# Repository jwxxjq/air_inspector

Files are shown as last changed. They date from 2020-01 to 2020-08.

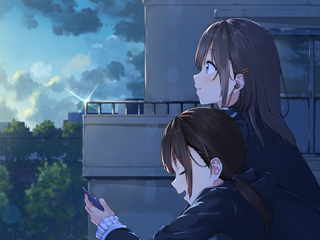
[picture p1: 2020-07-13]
host_pc_script/fig0.png

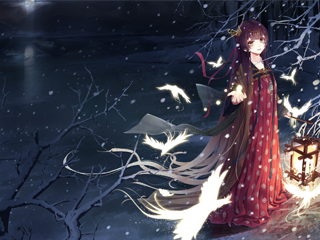
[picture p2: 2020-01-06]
host_pc_script/fig4.png

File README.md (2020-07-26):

# air_inspector
indoor air quility inspector for PM2.5/PM10/CO2/CH2O/TEMP/RH

comptable with self-build ESPEasy version: https://github.com/jwxxjq/ESPEasy

hardware:

    Temperature Sensor: SHT31
    
    Dust Sensor: PMS7003
    
    CH2O Sensor: ZE08
    
    CO2 Sensor: MH-Z19B

    mcu: ATmega328P (running Arduino)

    displayer: 320*240 ILI9341

    flash: W25Q16JVSSIG

    wifi connector: ESP8266

lib necessary:

    python:

        serial
  
        matplotlib
  
    Arduino:

        SPIMemory
  
        Adafruit_ILI9341
        
        Adafruit_GFX_Library
        
        Adafruit_SHT31
        
        MHZ19
        
        PMS
        
PCB projcet:

    https://oshwhub.com/jwxxjq/air_inspector

STEPS:

1. write fig data into flash

    A. prepare fig0~9.png (must be 240*320)
  
    B. excute host_pc_script/trans_png_to_bin.py, output figx.bin
    
    C. edit host_pc_script/uart_write.py
    
        a. COM port @ line 25
    
        b. baud rate @ line 27 (should match step D)
    
        c. do not excute right now
  
    D. edit uart_write_flash/uart_write_flash.ino
  
        a. BAUD_TATE @ line 6 (should match step C above)
    
        b. load into MCU
    
        c. then excute host_pc_script/uart_write.py, wait all lines finish
    
    E. if checksum error happens, may need to slow down the baud rate
  
2. load main program to MCU

    A. load air_inspector/air_inspector.ino to MCU
    
3. flash ESP8266 with this version: https://github.com/jwxxjq/ESPEasy

    A. select Environment - custom_sensor in Devices page, RX pin: 3, TX pin: 1
    
    B. other settings same with orginal ESPEasy(https://github.com/letscontrolit/ESPEasy) (like MQTT or others)

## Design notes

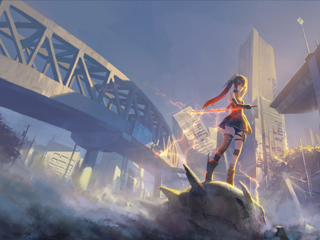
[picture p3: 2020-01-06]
host_pc_script/fig1.png

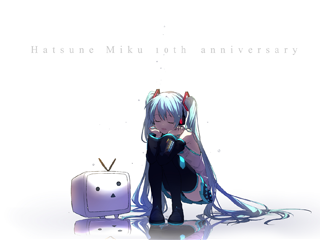
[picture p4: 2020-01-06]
host_pc_script/fig8.png

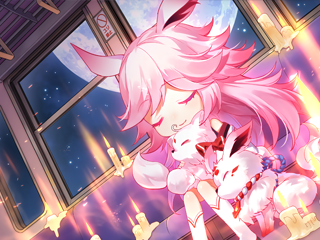
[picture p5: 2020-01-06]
host_pc_script/fig7.png

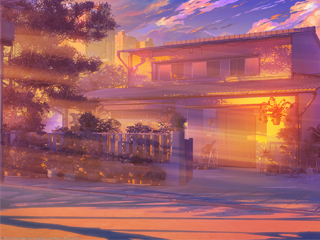
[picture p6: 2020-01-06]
host_pc_script/fig5.png

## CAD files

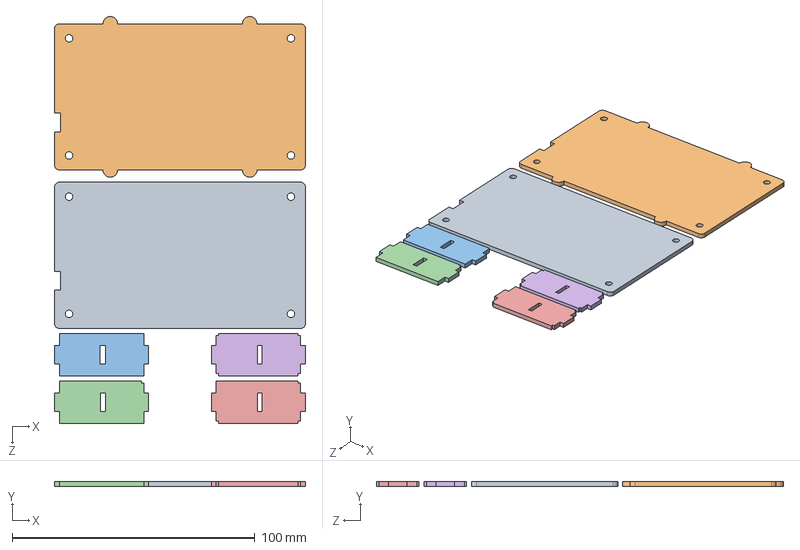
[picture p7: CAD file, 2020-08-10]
shell/compose_for_cut.SLDASM
103.5 x 2.00 x 167.8 mm
back
front
side
side_2
side_4
side_5

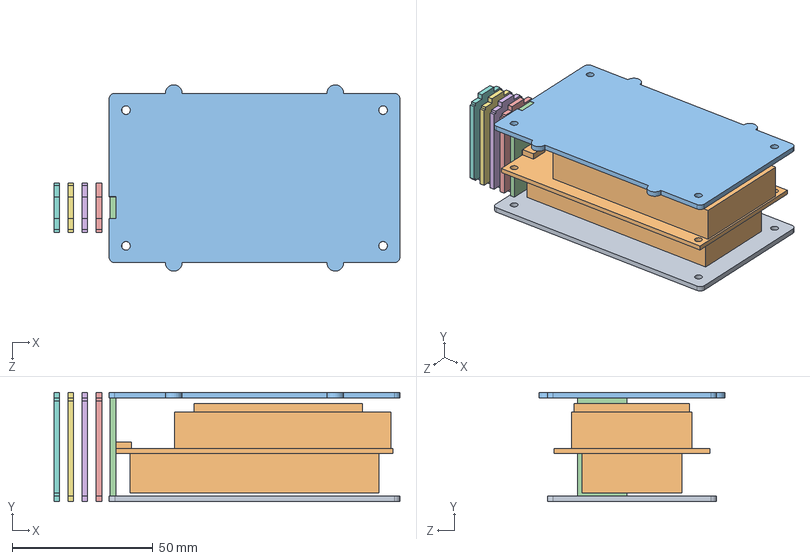
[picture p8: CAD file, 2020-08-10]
shell/assembly.SLDASM
123.1 x 38.8 x 66.3 mm
back
main_board
front
side
side_2
side_3
side_4
side_5

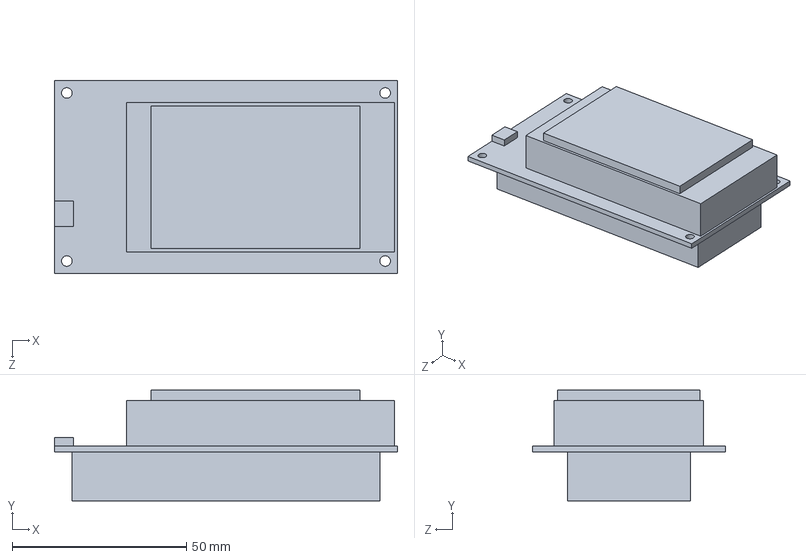
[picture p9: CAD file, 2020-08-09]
shell/main_board.SLDPRT
98.6 x 31.8 x 55.4 mm

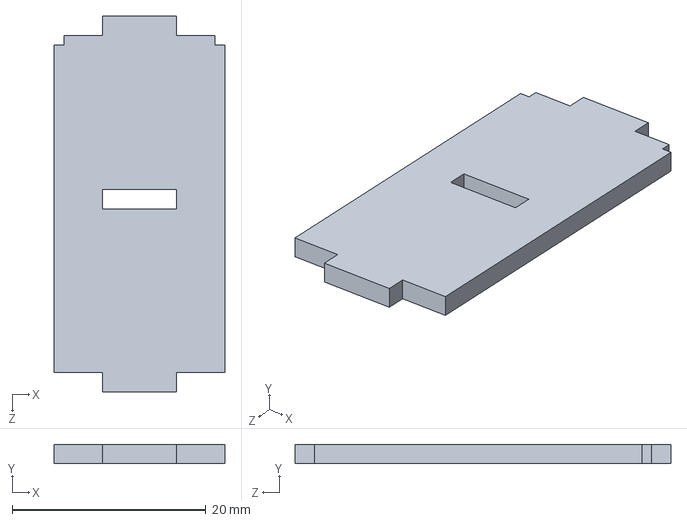
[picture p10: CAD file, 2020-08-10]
shell/side_3.SLDPRT
17.6 x 2.00 x 38.8 mm

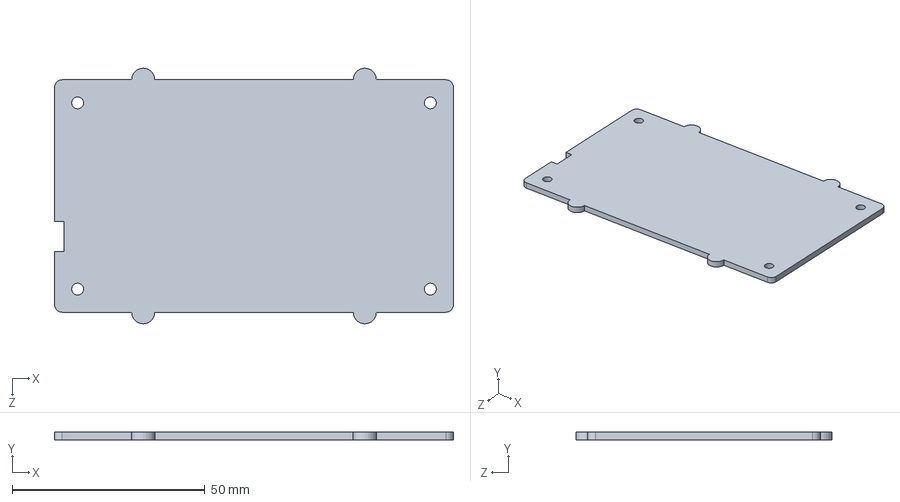
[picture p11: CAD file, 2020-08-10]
shell/front.SLDPRT
103.5 x 2.00 x 66.3 mm

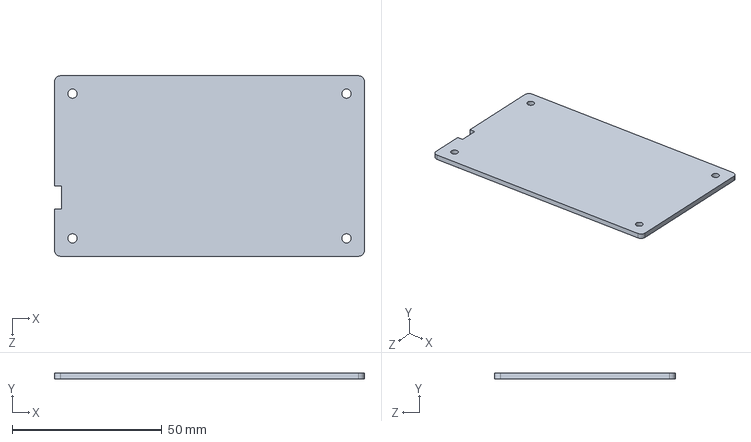
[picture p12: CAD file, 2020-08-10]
shell/back.SLDPRT
103.5 x 2.00 x 60.3 mm

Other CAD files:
shell/side_5.SLDPRT
shell/side_2.SLDPRT
shell/side_4.SLDPRT
shell/side.SLDPRT
shell/compose_for_cut.DWG
shell/compose_for_cut.SLDDRW

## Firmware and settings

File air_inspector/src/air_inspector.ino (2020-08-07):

#include "define.h"
#include "stdlib.h"

//TW07ST u_TW07ST;
SERSOR_SERIAL u_SERSOR_SERIAL(3,2);
MHZ19_SW_UART mhz19_sw_uart(8,7);
display_flash u_display_flash;
Adafruit_SHT31 sht31 = Adafruit_SHT31();
sensor_group u_sensor_value_group;
PMS7003_UART pms(14, 15);
ZE08_CH2O u_ZE08(5,6); //5: RXM, 6: TXM

unsigned long last_update_fig_time;
bool flag_to_update_fig; //set ture when need to update fig; set to false when one fig is updated
bool sensor_enable;

void setup() {
  // put your setup code here, to run once:
  //display related
  Serial.begin(BAUD_RATE); // for debug print
  u_display_flash.init();
  
  sensor_power_on();
  //sensor init
  sht31.begin(0x44); //SHT31 init
  Serial.println("sht31 init done");

  mhz19_sw_uart.init();
  Serial.println("mhz19 init done");
  pms.init();
  Serial.println("pms init done");
  u_ZE08.init();
  Serial.println("ZE08_CH2O init done");
  u_sensor_value_group.init();

  //set timer to update backgroud fig
  flag_to_update_fig = false;
  last_update_fig_time = millis();
  Serial.println(last_update_fig_time);

  //set sensor enable
  sensor_enable = true;

  //init timer1 for LED_PWM control
  LED_PWM_timer1_init();
}

void loop() {
//  update_LED_PWM_level();
  AIR_INSPECTOR_UART_DEBUG_PRINTLN("enter loop");
  while(1){
    for (uint8_t i = 0; i < max_fig_number; i++){
      AIR_INSPECTOR_UART_DEBUG_PRINT("fig");
      AIR_INSPECTOR_UART_DEBUG_PRINTLN(i);
//      uint8_t data[2] = {1,1};
//      u_display_flash.write_bytes_to_flash(1022, data, 2);
//      Serial.println(u_display_flash.read_one_byte_from_flash(1023));

//      uint8_t data = u_display_flash.read_one_byte_from_flash(1023);
//      Serial.print("current data = ");
//      Serial.println(data);
//      data += 1;
//      u_display_flash.write_bytes_to_flash(1023, &data, 1);
//      Serial.print("write data = ");
//      Serial.println(u_display_flash.read_one_byte_from_flash(1023));
//      while(1);

      u_display_flash.update_one_fig(i);
      //set default to all-zeros
      u_display_flash.update_item_value(i, item_number_CO2,  0);
      u_display_flash.update_item_value(i, item_number_CH2O, 0);
      u_display_flash.update_item_value(i, item_number_PM25, 0);
      u_display_flash.update_item_value(i, item_number_PM10, 0);
      u_display_flash.update_item_value(i, item_number_TEMP, 0);
      u_display_flash.update_item_value(i, item_number_RH,   0);

      //update real value display
      while(!flag_to_update_fig){
        //Serial.println("waiting for sensor update");
        if (u_sensor_value_group.TEMP_value != 0 && u_sensor_value_group.RH_value != 0){
          u_display_flash.update_item_value(i, item_number_TEMP, u_sensor_value_group.TEMP_value);
          u_display_flash.update_item_value(i, item_number_RH, u_sensor_value_group.RH_value);
          u_display_flash.update_item_value(i, item_number_CO2, u_sensor_value_group.CO2_value);
          u_display_flash.update_item_value(i, item_number_PM25, u_sensor_value_group.PM25_value);
          u_display_flash.update_item_value(i, item_number_PM10, u_sensor_value_group.PM10_value);
          u_display_flash.update_item_value(i, item_number_CH2O, u_sensor_value_group.CH2O_value);
        }
        check_if_update_fig();
        update_sensor_values();

        wait_next_sensor_update(); //delay time here
        update_sensor_enable();
      }
      flag_to_update_fig = false;
      //tft.fillScreen(ILI9341_BLACK);
    }
  }
}

//read enable pin to init / disable sensor
void update_sensor_enable(){
  int temp = analogRead(7);

  if (temp > 1000){ //enable pin pull high
    if (sensor_enable){
      //enable -> enable, do nothing
      sensor_enable = true;
    }
    else{
      //disable -> enable, turn on sensor
      sensor_enable = true;
      sensor_power_on();
      delay(10);

      pms.wakeup();
      mhz19_sw_uart.init();
      u_ZE08.init();
      //AIR_INSPECTOR_UART_DEBUG_PRINTLN("sensor wakeup done");
    }
  }
  else{
    if (sensor_enable){
      //enable -> disable, enter low power
      sensor_enable = false;
      //turn off sensor power
      sensor_power_off();
      pms.sleep(); //set pms into sleep
      //delay(10);
      //AIR_INSPECTOR_UART_DEBUG_PRINTLN("enter low power mode done");
    }
    else{
      //disable -> disable, do nothing
      sensor_enable = false;
    }
  }
}
//sensor enable set
void sensor_power_on(){
  pinMode(17, OUTPUT);
  digitalWrite(17, HIGH);
}

void sensor_power_off(){
  pinMode(17, OUTPUT);
  digitalWrite(17, LOW);
}

//delay time for sensor update
//should adjust LED_PWM inside
void wait_next_sensor_update(){
  unsigned long enter_delay_time = millis();
  while(1){
    update_LED_PWM_level();
    delay(500);
    unsigned long this_time = millis();
    if (enter_delay_time + sensor_read_delay_ms < this_time){
      //AIR_INSPECTOR_UART_DEBUG_PRINTLN(enter_delay_time + sensor_read_delay_ms);
      break;
    }
    else if (enter_delay_time > this_time){
      break; //directly break when millis() return to 0x0
    }
  }
}

//set update flag to ture
void set_update_fig_flag(){
  flag_to_update_fig = true;
}

//check time duration for update fig
void check_if_update_fig(){
//  Serial.println("in check function");
  unsigned long this_time = millis();
  //AIR_INSPECTOR_UART_DEBUG_PRINTLN(this_time);
  //AIR_INSPECTOR_UART_DEBUG_PRINTLN(last_update_fig_time);
  if (this_time - last_update_fig_time > time_each_fig_ms){
    set_update_fig_flag();
    last_update_fig_time = this_time;
  }
  else if ((this_time < time_each_fig_ms) && (last_update_fig_time > time_each_fig_ms)){ // back to 0 about 50 days
    set_update_fig_flag();
    last_update_fig_time = this_time;
  }
}

void update_sensor_values(){
  //temperature & humidity
  float t = sht31.readTemperature();
  float h = sht31.readHumidity();
  uint16_t temp = uint16_t (t*100);
  uint16_t rh = uint16_t (h*100);
  u_sensor_value_group.put_temp_rh_value(temp, rh);
  
  if (sensor_enable) {
    //delay(500);
    //CO2
    //AIR_INSPECTOR_UART_DEBUG_PRINTLN("start CO2");
    uint32_t CO2_value = mhz19_sw_uart.read_CO2_value();
    AIR_INSPECTOR_UART_DEBUG_PRINT("CO2_value = ");
    AIR_INSPECTOR_UART_DEBUG_PRINTLN(CO2_value);
    if (CO2_value != 15000 && CO2_value != 0 && CO2_value != 0xffffffff){  //not 0 & 15000 & time_out
      u_sensor_value_group.put_CO2_value(CO2_value);
    }
  
    delay(500);
    //dust: PM2.5 & PM10
    //AIR_INSPECTOR_UART_DEBUG_PRINTLN("start dust");
    if (pms.update_dust_value()){
      u_sensor_value_group.put_dust_value(pms.PM25_value,pms.PM10_value);
      AIR_INSPECTOR_UART_DEBUG_PRINT("PM2.5 value = ");
      AIR_INSPECTOR_UART_DEBUG_PRINTLN(pms.PM25_value);
      AIR_INSPECTOR_UART_DEBUG_PRINT("PM10 value = ");
      AIR_INSPECTOR_UART_DEBUG_PRINTLN(pms.PM10_value);
    }
  
    delay(500);
    //CH2O
    //AIR_INSPECTOR_UART_DEBUG_PRINTLN("start CH2O");
    uint16_t CH2O_value = u_ZE08.read_CH2O_value();
    AIR_INSPECTOR_UART_DEBUG_PRINT("CH2O value = ");
    AIR_INSPECTOR_UART_DEBUG_PRINTLN(CH2O_value);
    if (CH2O_value != 0){  //heating return 0x0
      u_sensor_value_group.put_CH2O_value(CH2O_value);
    }
  }
  else{
    AIR_INSPECTOR_UART_DEBUG_PRINTLN("sensor disabled");
  }

  u_sensor_value_group.calculate_average_value();

  u_SERSOR_SERIAL.print_value(u_sensor_value_group.PM25_value, u_sensor_value_group.PM10_value,
                              u_sensor_value_group.CO2_value, u_sensor_value_group.CH2O_value,
                              u_sensor_value_group.TEMP_value, u_sensor_value_group.RH_value);

}

//timer init for LED_PWM
void LED_PWM_timer1_init(){
  pinMode(9, OUTPUT);

  #ifdef disable_LED_PWM
    digitalWrite(9, HIGH);
    AIR_INSPECTOR_UART_DEBUG_PRINTLN("LED_PWM disabled");
  #else
    #ifdef use_HW_LED_PWM
      analogWrite(9, 255);
      AIR_INSPECTOR_UART_DEBUG_PRINTLN("USE HW PWM");
    #else
      TCCR1A = 0;
      TCCR1B = 0;
      TCCR1B |= (1 << CS10) | (1 << WGM12); // CS10 -- prescaler 1, WGM12 -- CTC mode
      TIMSK1 = 0;
      TIMSK1 |= (1 << OCIE1A) | (1 << OCIE1B); // OCIE1A -- OCR1A, OCIE1B -- OCR1B
      OCR1A = MCU_xtal_freq / LED_PWA_freq - 1; // set OCR1A value, which return 0 in next cycle, change PB9 to high
      OCR1B = MCU_xtal_freq / LED_PWA_freq / 100 * 50 - 1; // set OCR1B, this will change PB9 to low, default set to 50%
    #endif
  #endif
}

//change LED PWM cycle
void LED_PWM_set(uint8_t PWM_precentage){
  if (PWM_precentage >= 100){
    PWM_precentage = 100; //max 100%
  }
  OCR1B = MCU_xtal_freq / LED_PWA_freq / 100 * PWM_precentage - 1; // set to PWA_precentage %
}

ISR(TIMER1_COMPA_vect) {
  PORTB |= B00000010; // pin 9 set HIGH
}
 
ISR(TIMER1_COMPB_vect) {
  PORTB &= B11111101; // pin 9 set LOW
}

void update_LED_PWM_level(){
  #ifdef disable_LED_PWM
    digitalWrite(9, HIGH);
  #else
    int temp = analogRead(6);
    //AIR_INSPECTOR_UART_DEBUG_PRINT("light: ");
    //AIR_INSPECTOR_UART_DEBUG_PRINTLN(temp);

    uint8_t index = 0;
    uint8_t index_max = sizeof(LED_light_in_threshold)/sizeof(LED_light_in_threshold[0]);
    //AIR_INSPECTOR_UART_DEBUG_PRINTLN(index_max);
    for(index = 0; index < index_max; index++){
      int threhold_value = LED_light_in_threshold[index]<<2;
      if (temp > threhold_value){
        continue;
      }
      else{
        //AIR_INSPECTOR_UART_DEBUG_PRINTLN(index);
        break;
      }
    }
    //AIR_INSPECTOR_UART_DEBUG_PRINT("set LED_PWM to level");
    //AIR_INSPECTOR_UART_DEBUG_PRINTLN(index);

    #ifdef use_HW_LED_PWM
      analogWrite(9, LED_birghtness[index]);
    #else
      LED_PWM_set(LED_birghtness[index]);
    #endif
  #endif
}

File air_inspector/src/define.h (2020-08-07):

#ifndef _DEFINE_
#define _DEFINE_

#include <SoftwareSerial.h>
//#include "TW07ST.h"
//#include <FlexiTimer2.h>
#include <SENSOR_SERIAL.h>
#include <display_flash.h>
#include <Adafruit_SHT31.h>
#include <sensor_group.h>
#include <MHZ19_SW_UART.h>
#include <PMS7003.h>
#include <ZE08_CH2O.h>

//Arduino peri define
#define BAUD_RATE 9600 //for serial.print

//#define disable_LED_PWM //uncomment here to disable LED_TFT PWM auto brightness adjust feature
#define use_HW_LED_PWM //HW PWM 500Hz

#define AIR_INSPECTOR_UART_DEBUG
/* Setup debug printing macros. */
#define AIR_INSPECTOR_UART_DEBUG_PRINTER Serial
#ifdef AIR_INSPECTOR_UART_DEBUG
  #define AIR_INSPECTOR_UART_DEBUG_PRINT(...) { AIR_INSPECTOR_UART_DEBUG_PRINTER.print(__VA_ARGS__); }
  #define AIR_INSPECTOR_UART_DEBUG_PRINTLN(...) { AIR_INSPECTOR_UART_DEBUG_PRINTER.println(__VA_ARGS__); }
#else
  #define AIR_INSPECTOR_UART_DEBUG_PRINT(...) {} /**< Debug Print Placeholder if Debug is disabled */
  #define AIR_INSPECTOR_UART_DEBUG_PRINTLN(...) {} /**< Debug Print Line Placeholder if Debug is disabled */
#endif

//fig fresh rate
#define time_each_fig_ms 1800000 //30*60*1000ms
//#define time_each_fig_ms 18000 //30*60*1000ms

//sensor value update rate
#define sensor_read_delay_ms 10000 //10*1000ms

//timer1 TFT_LED PWM config
#define MCU_xtal_freq 16000000
#define LED_PWA_freq 1000 //1k PWM
#ifndef use_HW_LED_PWM
  const uint8_t LED_birghtness[7] = {10, 20, 30, 40, 50, 70, 99}; //100 level
#else
//  const uint8_t LED_birghtness[7] = {40, 80, 130, 160, 190, 230, 255}; //255 level for HW PWM
  const uint8_t LED_birghtness[7] = {90, 95, 100, 105, 110, 115, 150}; //255 level for HW PWM
#endif
const uint8_t LED_light_in_threshold[6] = {40, 60, 75, 100, 125, 150}; //*4 to convert to 0~1023

#endif

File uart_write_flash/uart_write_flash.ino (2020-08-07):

#include<SoftwareSerial.h>
#include<SPIMemory.h>
#define fig_width 320
#define fig_high 240
#define BAUD_RATE 9600 //for serial.print
#define TRANS_BAUD_RATE 76800 //for softSerial
#define FLASH_CS 4 //define cs pin of flash
//#define fig_byte_number fig_high*fig_width*2 //r5g6b5, each pixel occupy 2 byte, 153600 bytes for 240*320*2
#define fig_byte_number 153664
#define max_fig_number 10
#define flash_max_size 0x200000 //2MB(16Mbit)
#define flash_size_each_fig 0x30000 //192K > 153600

#define char_lib_width 96
#define char_lib_high 200
#define char_lib_start_addr 0x1FB000 //0x1f_b000~0x1f_fb00
#define char_lib_byte_number 19200

//#define fig1_start_addr flash_max_size - 0x30000*1 //0x0 ~ 0x‭25800‬ for 240*320*2
SPIFlash flash(FLASH_CS);
SoftwareSerial softSerial(3,2);

void setup() {
  // put your setup code here, to run once:
  Serial.begin(BAUD_RATE);
  softSerial.begin(TRANS_BAUD_RATE);
  softSerial.listen();
  flash.begin();
//  uint8_t test;
//  uint32_t addr = char_lib_start_addr+0x5;
//  Serial.println(addr);
//  Serial.println(flash.readByte(addr));
//  
//  addr = char_lib_start_addr+0x4843;
//  Serial.println(addr);
//  Serial.println(flash.readByte(addr));
}

void loop() {
  // put your main code here, to run repeatedly:
  Serial.println("waiting for start");
  for (uint8_t fig_count = 0; fig_count < max_fig_number; fig_count ++){
    uint32_t byte_count = 0;
    uint32_t flash_start_addr = flash_max_size - (flash_size_each_fig * fig_count) - flash_size_each_fig;
    uint32_t offset = 0;
    while(1){
      if (softSerial.available() > 5){
        //erase flash here instead of in setup(), in case of mistach reset putton
        if (erase_flash(flash_start_addr, fig_byte_number) != true){
          Serial.println("flash erase error");
          while(1);
        }
  //      flash.eraseSection(flash_start_addr, 65536);
  //      flash.eraseSection(flash_start_addr+65536, 65536);
        //flash.eraseChip();
        break;
      }
    }
    Serial.println("flash erase done");
    while(byte_count < fig_byte_number){

      if(softSerial.available() > 31){
        uint8_t data[32];
        bool result;
        softSerial.readBytes(data, 32);
        result = flash.writeByteArray(flash_start_addr+offset, data, 32); // write 32 byte to flash
        if (result != true) {
          Serial.print("write flash error @ ");
          Serial.println(offset);
        }
        uint8_t read_data[32];
        result = flash.readByteArray(flash_start_addr+offset, read_data, 32);
        if (result != true) {
          Serial.println("read flash error @");
          Serial.println(offset);
        }
        softSerial.write(summary(read_data));
        offset += 32;
        byte_count += 32;
      }
    }
    Serial.println("one fig done");
  }
  
  Serial.println("write char_lib start");
  uint32_t byte_count = 0;
  uint32_t flash_start_addr = char_lib_start_addr;
  uint32_t offset = 0;
  while(1){
    if (softSerial.available() > 5){
      //erase flash here instead of in setup(), in case of mistach reset putton
      if (erase_flash(flash_start_addr, char_lib_byte_number) != true){
        Serial.println("flash erase error");
        while(1);
      }
      break;
    }
  }
  Serial.println("flash erase done");
  while(byte_count < char_lib_byte_number){
    if(softSerial.available() > 31){
      uint8_t data[32];
      bool result;
      softSerial.readBytes(data, 32);
      result = flash.writeByteArray(flash_start_addr+offset, data, 32); // write 32 byte to flash
      if (result != true) {
        Serial.print("write flash error @ ");
        Serial.println(offset);
      }
      uint8_t read_data[32];
      result = flash.readByteArray(flash_start_addr+offset, read_data, 32);
      if (result != true) {
        Serial.println("read flash error @");
        Serial.println(offset);
      }
      softSerial.write(summary(read_data));
      offset += 32;
      byte_count += 32;
    }
  }
  Serial.print("write char lib done");
  while(1);
}

uint8_t summary(uint8_t* data){
  uint8_t result = 0;
  for (uint8_t i = 0; i<32; i++){
    result += data[i];
  }
  return result;
}

bool erase_flash(uint32_t start_addr, uint32_t length){
  uint32_t current_start_addr = start_addr;
  bool result = true;
  uint32_t erase_length = 0;
  Serial.print("erase start addr: ");
  Serial.println(start_addr);
  Serial.print("size: ");
  Serial.println(length);
  while(length > 0){
    if(length > 65536){
      //length > 64KB
      erase_length = 65536;
      if (flash.eraseBlock64K(current_start_addr) != true){
        result = false;
      }
    }
    else if (length > 32768){
      erase_length = 32768;
      if (flash.eraseBlock32K(current_start_addr) != true){
        result = false;
      }
    }
    else if (length > 4096){
      erase_length = 4096;
      if (flash.eraseSector(current_start_addr) != true){
        result = false;
      }
    }
    else{
      erase_length = length;
      if (flash.eraseSection(current_start_addr, length) != true){
        result = false;
      }
    }
    
    current_start_addr += erase_length;
    length -= erase_length;
    Serial.print("erase length remaining: ");
    Serial.println(length);
  }
  return result;
}

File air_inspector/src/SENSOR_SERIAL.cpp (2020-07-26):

#include "SENSOR_SERIAL.h"

//public
SERSOR_SERIAL::SERSOR_SERIAL(){
  TX_pin = SENSOR_SERIAL_default_TX_pin;
  RX_pin = SENSOR_SERIAL_default_RX_pin;
  SENSOR_SERIAL_DEBUG_PRINTLN("using default TX/RX pin for Sensor print");
}

SERSOR_SERIAL::SERSOR_SERIAL(int8_t RX_pin_in, int8_t TX_pin_in){
  TX_pin = TX_pin_in;
  RX_pin = RX_pin_in;
  SENSOR_SERIAL_DEBUG_PRINTLN("using TX_pin = ");
  SENSOR_SERIAL_DEBUG_PRINTLN(TX_pin);
  SENSOR_SERIAL_DEBUG_PRINTLN("using RX_pin = ");
  SENSOR_SERIAL_DEBUG_PRINTLN(RX_pin);
}

void SERSOR_SERIAL::print_value(uint16_t PM2_5_value, uint16_t PM10_value, uint16_t CO2_value, uint16_t HCHO_value, uint16_t Temperature_value, uint16_t Humidity_value){
  SoftwareSerial SENSOR_SERIAL_serial(RX_pin, TX_pin);
  //Serial.begin(9600);
  uint8_t Temperature_value_high_byte = Temperature_value/100;
  uint8_t Temperature_value_low_byte = Temperature_value%100;
  uint8_t Humidity_value_high_byte = Humidity_value/100;
  uint8_t Humidity_value_low_byte = Humidity_value%100;

  uint16_t sum = SENSOR_SERIAL_SIG1 + SENSOR_SERIAL_SIG2;
  sum += PM2_5_value/256 + PM2_5_value%256;
  sum += PM10_value/256 + PM10_value%256;
  sum += CO2_value/256 + CO2_value%256;
  sum += HCHO_value/256 + HCHO_value%256;
  sum += Temperature_value_high_byte + Temperature_value_low_byte;
  sum += Humidity_value_high_byte + Humidity_value_low_byte;

  SENSOR_SERIAL_serial.begin(SENSOR_SERIAL_band_rate);
  SENSOR_SERIAL_serial.write(SENSOR_SERIAL_SIG1);
  SENSOR_SERIAL_serial.write(SENSOR_SERIAL_SIG2);
  SENSOR_SERIAL_serial.write(PM2_5_value>>8);
  SENSOR_SERIAL_serial.write(PM2_5_value);
  SENSOR_SERIAL_serial.write(PM10_value>>8);
  SENSOR_SERIAL_serial.write(PM10_value);
  SENSOR_SERIAL_serial.write(CO2_value>>8);
  SENSOR_SERIAL_serial.write(CO2_value);
  SENSOR_SERIAL_serial.write(HCHO_value>>8);
  SENSOR_SERIAL_serial.write(HCHO_value);
  SENSOR_SERIAL_serial.write(Temperature_value_high_byte);
  SENSOR_SERIAL_serial.write(Temperature_value_low_byte);
  SENSOR_SERIAL_serial.write(Humidity_value_high_byte);
  SENSOR_SERIAL_serial.write(Humidity_value_low_byte);
  SENSOR_SERIAL_serial.write(sum>>8);
  SENSOR_SERIAL_serial.write(sum%256);
  
  SENSOR_SERIAL_serial.end();
}

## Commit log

2019-12-30 fix error & tft display test pass
    fix png_2_bin.py error; ari_inspector.ino now can display 3 figs in turns
    [air_inspector.ino, define.h, trans_png_to_bin.py]
2020-01-07 update uart write & read position from flash
    update uart write .bin to support new .bin size.
    update air_inspector.ino to support read number position from flash
2020-02-16 finish value display function
    finish value display functon, now can display fig, display and refresh value number.
    next step to finish sensor lib.
2020-02-16 update readme for current status
    remove unused file and udpate readme
2020-04-12 add TW07ST lib
    TW07ST main sensor lib finish
2020-04-12 merge sensor calling to main code
    merge TW07ST code to main code
2020-05-15 add sensor serial output function
    add serial output sensor data to EasyESP.
2020-06-19 Update README.md
    change sensor plan
2020-06-28 add TFT LED_birghtness control
    using PWM api (using timer1) to control TFT LED_birghtness
2020-07-12 add Gerber PCB
2020-07-26 update PCB project link
    add PCB project link & gerber zip
2020-07-26 remove LED_PWM & update code
    finish all sensor api & main code
2020-07-28 update LED_PWM
    add HW/interrupt LED PWM with known bug, could use define to switch to different LED mode
    [air_inspector.ino, define.h, display_flash.h]
2020-08-07 update write flash bandrate
    UART rate 57600 -> 76800 for speedup
2020-08-07 add sensor enable api
    add sensor enable api.
    EasyESP control test pass, sensors can enter sleep(low power) and wakeup.
2020-08-07 add v1.1 PCB
2020-08-09 add solidworks files
    add 3D shell files
    [assembly.SLDASM, back.SLDPRT, front.SLDPRT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]
2020-08-10 add DWG for machining
    DWG ready for machining
    [assembly.SLDASM, back.SLDPRT, compose_for_cut.DWG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]
